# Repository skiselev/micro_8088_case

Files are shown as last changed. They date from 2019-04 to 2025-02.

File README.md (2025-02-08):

# Micro 8088 Case
Case for [Micro 8088](https://github.com/skiselev/micro_8088) and [ISA 8-Bit Backplane](https://github.com/skiselev/isa8_backplane) Based Computer

## Introduction
This case is intended to be used with [Micro 8088](https://github.com/skiselev/micro_8088)
and [ISA 8-Bit Backplane](https://github.com/skiselev/isa8_backplane) based computer.

The front panel features the standard [Intel* 9-pin front panel pinout](https://www.intel.com/content/www/us/en/support/articles/000007309/intel-nuc.html), and can work with other systems as well.

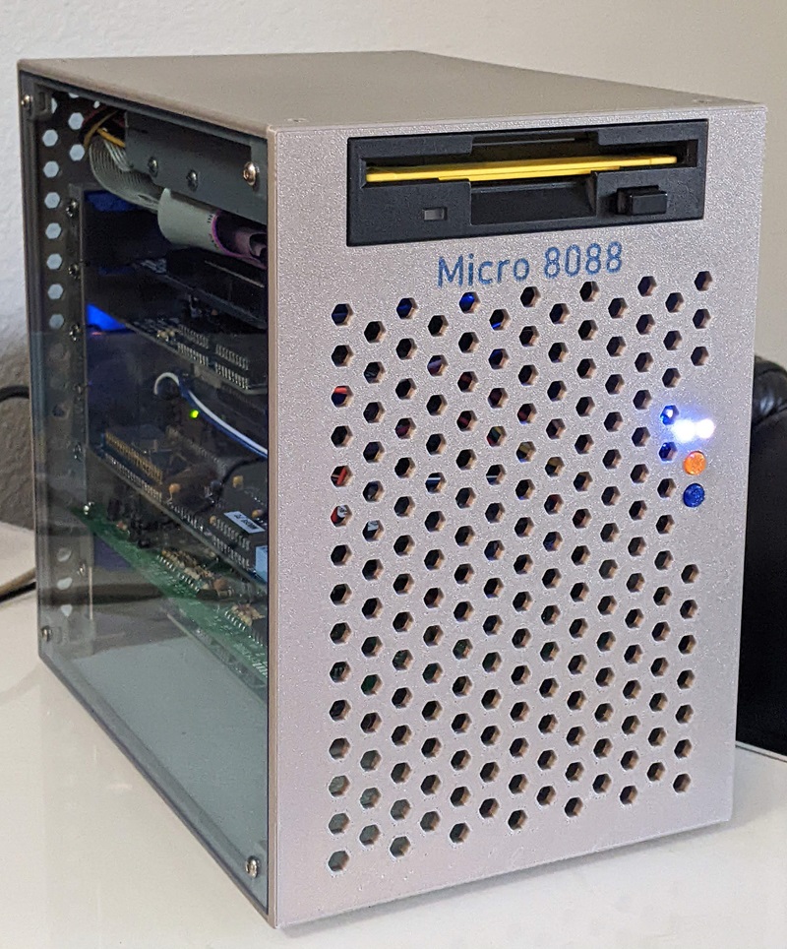
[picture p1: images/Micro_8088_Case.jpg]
Micro 8088 Case


## Hardware Documentation

### 3D Printed Parts

Parts can be printed using PETG or other fillament. The parts are designed to be printed without supports, with the exception of the case back, which needs supports for the DC power connector area.

Part            | File                                                                                               | Notes
--------------- | -------------------------------------------------------------------------------------------------- | ------------------------------------------------------------------
Case Front      | [case_front.stl](https://github.com/skiselev/micro_8088_case/blob/master/printed/case_front.stl)   | For the system name in colored letters, print sytem_name.stl first
Case Back       | [case_back.stl](https://github.com/skiselev/micro_8088_case/blob/master/printed/case_back.stl)     |
Case Bottom     | [case_bottom.stl](https://github.com/skiselev/micro_8088_case/blob/master/printed/case_bottom.stl) | Use supports on the build plate only option when printing
Case Top        | [case_top.stl](https://github.com/skiselev/micro_8088_case/blob/master/printed/case_top.stl)       | It is possible to use a 192.8 mm * 192.8 mm piece of transparent 1/8" / 3 mm acrylic plastic instead
Case Left       | [case_left.stl](https://github.com/skiselev/micro_8088_case/blob/master/printed/case_left.stl)     |
Case Right      | [case_right.stl](https://github.com/skiselev/micro_8088_case/blob/master/printed/case_right.stl)   |
ISA Slots Cover | [slots_cover.stl](https://github.com/skiselev/micro_8088_case/blob/master/printed/slots_cover.stl) | Snaps into the Case Back
Speaker Bracket | [speaker_bracket.stl](https://github.com/skiselev/micro_8088_case/blob/master/printed/speaker_bracket.stl) |
System Name     | [system_name.stl](https://github.com/skiselev/micro_8088_case/blob/master/printed/system_name.stl) | System Name "Micro 8088". Print and remove the rectangle on the perimeter. Next print case_front.stl
Keycaps         | [keycap_6mm_round.stl](https://github.com/skiselev/micro_8088_case/blob/master/printed/keycap_6mm_round.stl) | Print two using colorful plastic. It is recommended to print several keycaps at the time. [Omron B32-2000](https://www.mouser.com/ProductDetail/653-B32-2000) keycaps can be used instead

### Other Parts

Part                       | Quantity  | Notes
-------------------------- | --------- | -----
M3 x 8 mm flat head screws | 16        | Hold case sides together
M3 x 1.8 mm square nuts    | 16        | Hold case sides together
M3 x 8 mm pan head screws  | 6         | Floppy drive
M3 x 6 mm pan head screws  | 15        | Backplane - 6 screws, front panel - 2 screws, ISA cards - 7 screws

### Front Panel Schematic and PCB Layout

[Schematic - Version 1.0](KiCad/Micro_8088_Front_Panel-Schematic-1.0.pdf)

[PCB Layout - Version 1.0](KiCad/Micro_8088_Front_Panel-Board-1.0.pdf)

### Jumpers, Connectors, and Switches

#### J1 - Front Panel Connector
Pin | Description                  | Pin | Description
--- | ---------------------------- | --- | -------------------
1   | HDD Activity LED Anode (+)   | 2   | Power LED Anode (+)
3   |	HDD Activity LED Cathode (-) | 4   | Power LED Cathode (-)
5   |	Reset Switch (Ground)        | 6   | Power Switch (Output)
7   |	Reset Switch (Output)        | 8   | Power Switch (Ground)
9   |	5V (Unused)                  | 10  | Key (Pin removed)

#### SW1 - Power Switch
Press SW1 to turn on/off the system

#### SW2 - Reset Switch
Press SW2 to reset the system

### Front Panel Bill of Material

[Micro 8088 Front Panel project on Mouser.com](https://www.mouser.com/ProjectManager/ProjectDetail.aspx?AccessID=e9e37fe2f8) - View and order all components except of the PCB.
[Micro 8088 Front Panel project on OSH Park](https://oshpark.com/shared_projects/V4toeD34) - View and order the PCB.

Component type     | Reference | Description                       | Quantity | Possible sources and notes 
------------------ | --------- | --------------------------------- | -------- | --------------------------
PCB                |           | Micro 8080 Front Panel PCB V1.0   | 1        | OSH Park [Micro 8088 Front Panel V1.0](https://oshpark.com/shared_projects/V4toeD34)<br>Alternatively order from a PCB manufacturer of your choice using provided KiCad files
LED                | D1        | 3 mm, blue LED indicator          | 1        | Mouser [604-WP710A10QBC/D](https://www.mouser.com/ProductDetail/604-WP710A10QBC-D)<br>Alternatively use 3 mm green LED<br>Note: Intel* specifies a bi-color green/yellow LED
LED                | D2        | 3 mm, pink LED indicator          | 1        | Mouser [604-WP7104VRVCWA](https://www.mouser.com/ProductDetail/604-WP7104VRVCWA)<br>Alternatively use 3 mm yellow LED
Tactile Button     | SW1, SW2  | 6 mm tactile button, projected    | 2        | Mouser [653-B3F-1052](https://www.mouser.com/ProductDetail/653-B3F-1052), [653-B3F-1050](https://www.mouser.com/ProductDetail/653-B3F-1050)
Key Cap            | SW1, SW2  | Omron 6 mm round keycap, black    | 2        | Mouser [653-B32-2000](https://www.mouser.com/ProductDetail/653-B32-2000). Or use 3D printed keycaps
Pin Header         | J1        | 2x5 pin header, 2.54 mm pitch     | 1        | Mouser [855-M20-9980545](https://www.mouser.com/ProductDetail/855-M20-9980545)
Speaker            |           | 36 mm x 4.6 mm, 8 ohm, 1 W        | 1        | Mouser [665-AS03608MRLW100R](https://www.mouser.com/ProductDetail/665-AS03608MRLW100R)

### Front Panel Cables Bill of Material

Component type     | Reference | Description                           | Quantity      | Possible sources and notes 
------------------ | --------- | ------------------------------------- | ------------- | --------------------------
Connector          | J1        | 2x5 pin wire housing, 2.54 mm pitch   | 1             | Front panel connector. Mouser [855-M20-1070500](https://www.mouser.com/ProductDetail/855-M20-1070500)
Connector          |           | 4 pin wire housing, 2.54 mm pitch     | 2             | Speaker connector. Power switch and Power LED connector for the ISA 8-bit backplane. Mouser [855-M20-1060400](https://www.mouser.com/ProductDetail/855-M20-1060400)
Connector          |           | 2 pin wire housing, 2.54 mm pitch     | 2             | Reset switch connector. HDD LED connector. Mouser [855-M20-1060200](https://www.mouser.com/ProductDetail/855-M20-1060200)
Contact            |           | Female crimp contact                  | 20            | All connectors. Mouser [855-M20-1160042](https://www.mouser.com/ProductDetail/855-M20-1160042), [855-M20-1180042](https://www.mouser.com/ProductDetail/855-M20-1180042)
Wire               |           | 22 AWG - 26 AWG stranded wire, white  | 60 cm or 2'   | Negative wires for LEDs and switches
Wire               |           | 22 AWG - 26 AWG stranded wire, black  | 10 cm or 1/3' | Negative wire for the speaker
Wire               |           | 22 AWG - 26 AWG stranded wire, red    | 30 cm or 1'   | Positive wire for the speaker and the HDD LED
Wire               |           | 22 AWG - 26 AWG stranded wire, green  | 10 cm or 1/3' | Positive wire for the Power LED
Wire               |           | 22 AWG - 26 AWG stranded wire, blue   | 30 cm or 1'   | Positive wire for the Reset switch
Wire               |           | 22 AWG - 26 AWG stranded wire, yellow | 10 cm or 1/3' | Positive wire for the Power switch

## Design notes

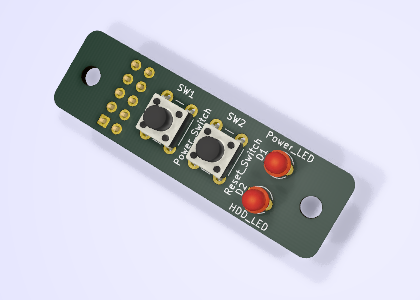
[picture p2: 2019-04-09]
images/Micro_8088_Front_Panel.png

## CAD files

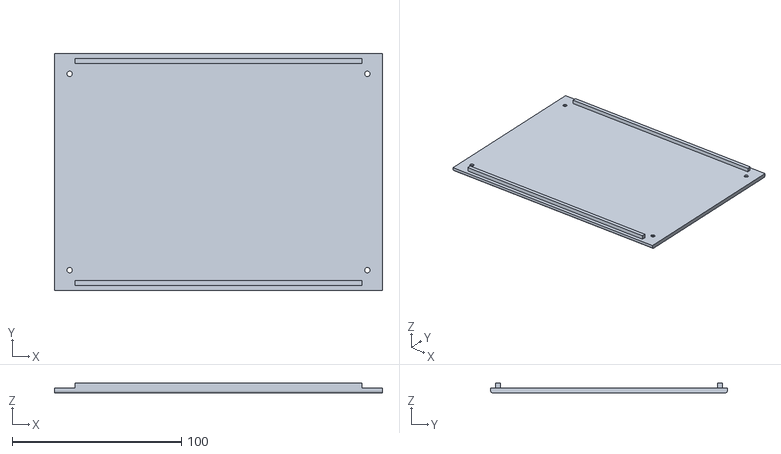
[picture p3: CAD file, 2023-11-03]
printed/case_left.stl
193.8 x 140.0 x 6.00

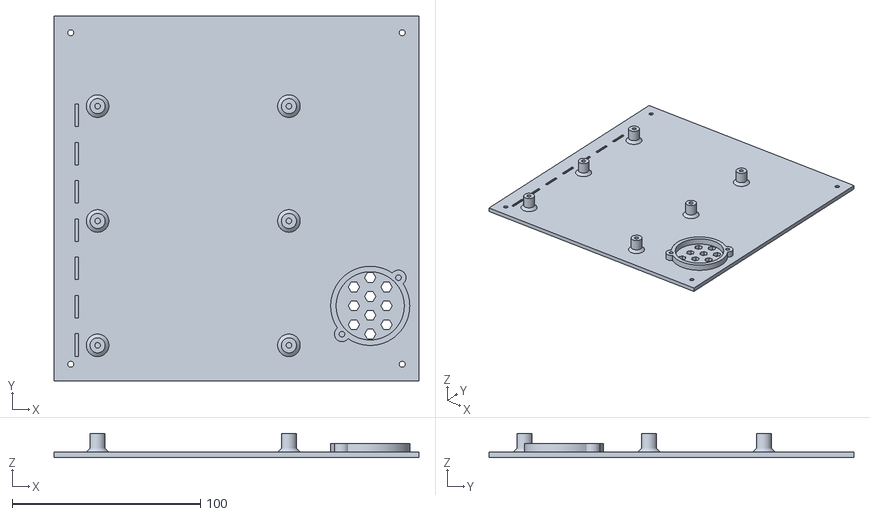
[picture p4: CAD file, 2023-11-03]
printed/case_bottom.stl
193.8 x 193.8 x 13.0

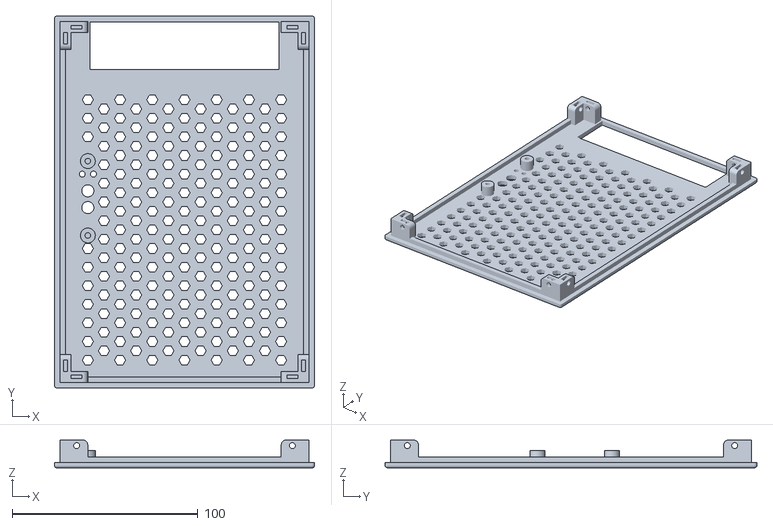
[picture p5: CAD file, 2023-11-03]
printed/case_front.stl
140.0 x 200.0 x 15.0

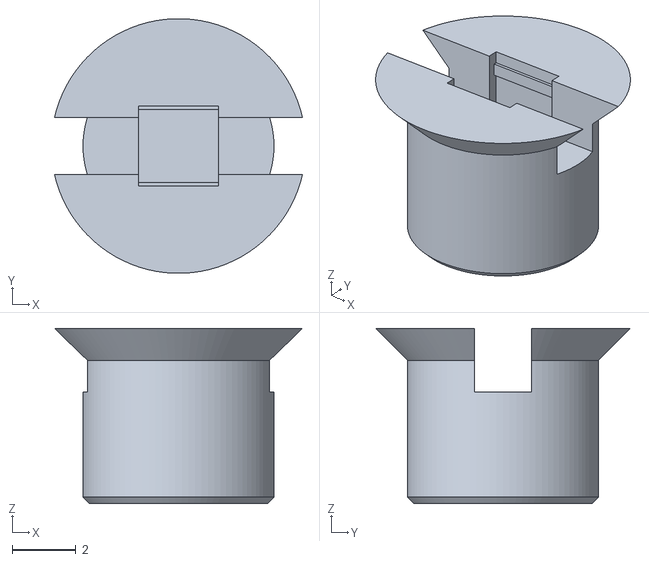
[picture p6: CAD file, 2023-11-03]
printed/keycap_6mm_round.stl
7.79 x 8.00 x 5.50

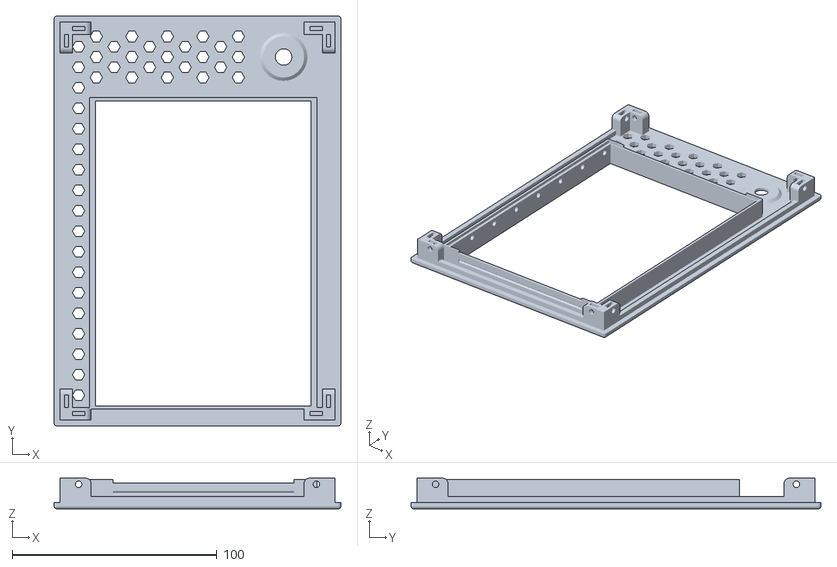
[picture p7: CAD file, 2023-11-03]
printed/case_back.stl
140.0 x 200.0 x 15.0

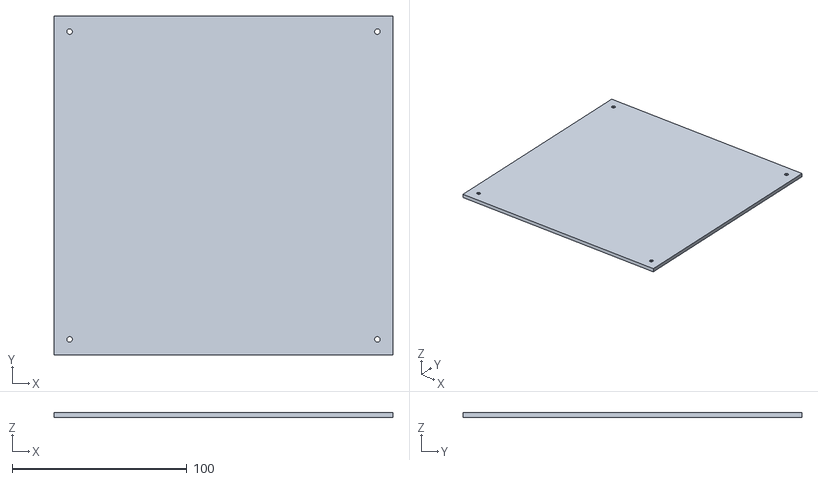
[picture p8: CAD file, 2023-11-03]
printed/case_top.stl
193.8 x 193.8 x 3.00

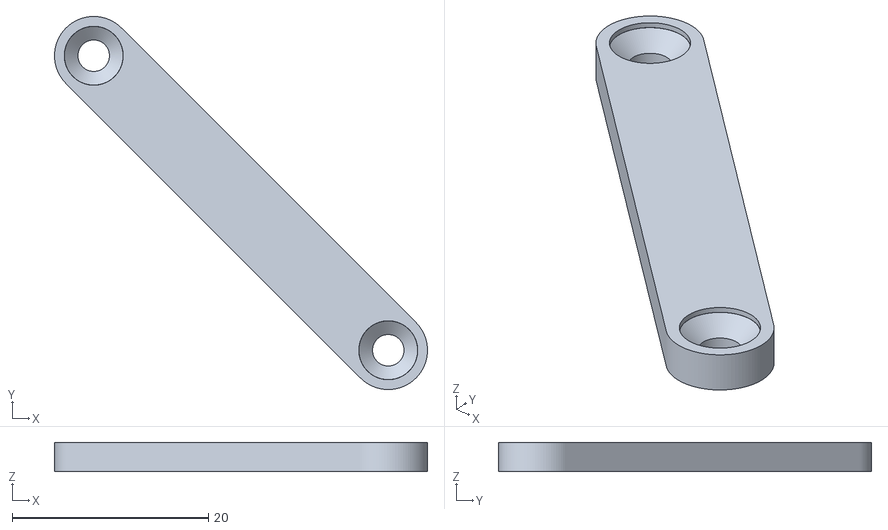
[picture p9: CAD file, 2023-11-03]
printed/speaker_bracket.stl
38.0 x 38.0 x 3.00

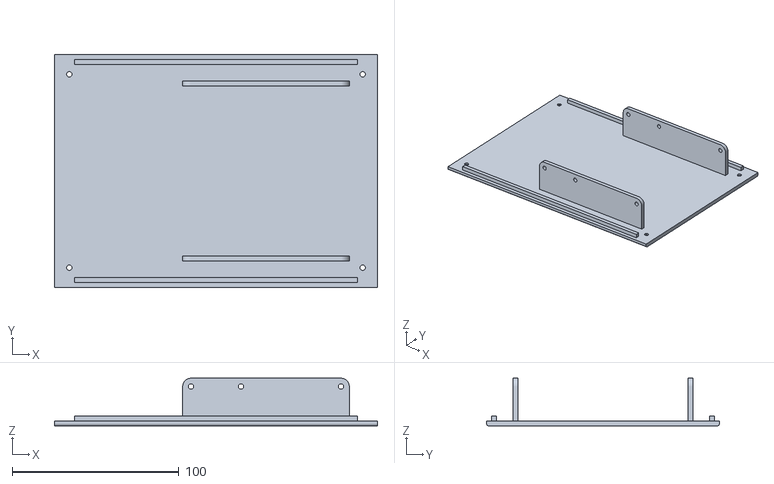
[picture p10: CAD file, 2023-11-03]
printed/case_right.stl
193.8 x 140.0 x 28.6

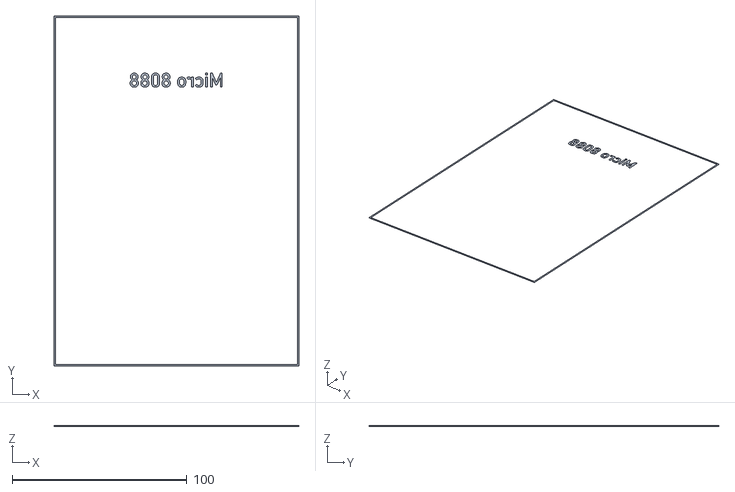
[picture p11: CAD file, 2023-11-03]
printed/system_name.stl
140.0 x 200.0 x 0.2

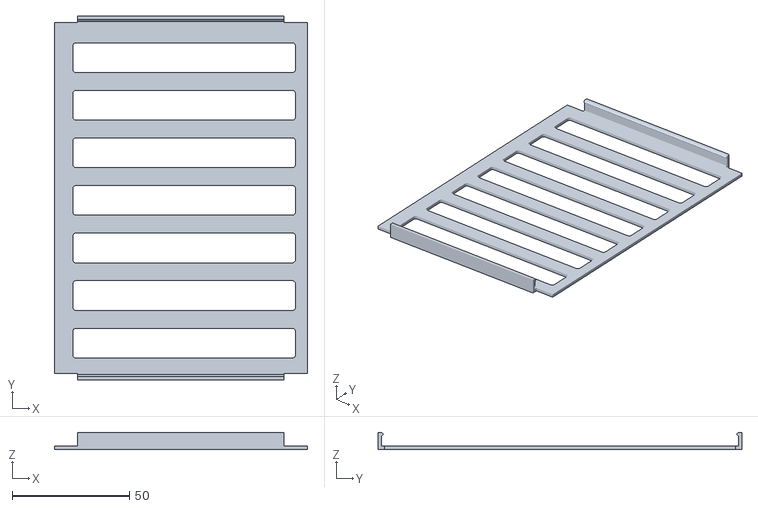
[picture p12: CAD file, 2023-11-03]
printed/slots_cover.stl
108.2 x 155.4 x 7.40

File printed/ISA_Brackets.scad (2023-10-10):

// ISA Bracket - Compatible with Keystone Electronics 9202
//
// Copyright (C) Sergey Kiselev <skiselev@gmail.com>
// Losely based on work by Arne Schmitz <arne.schmitz@me.com>

br_width = 18.4;
br_height = 120.02;
br_thick = 1.2;

cut_bottom_width = 4.11;
cut_bottom_height = 7.5;
//tolerance = 0.1;

br_height_wo_tongue = 112.78;
tongue_height = (br_height - br_height_wo_tongue);
tongue_width = 10.2;
tongue_cut_width = (br_width-tongue_width)/2;

tab_width=18.8;
tab_length=11.4;

cut_left_height=6;
cut_left_width=2.8;

append_right_height=2.5; // 3.2;
append_right_width=cut_left_width+tab_width-br_width;

tab_hole_diameter = 4.4;
tab_hole_y = tab_length+br_thick-6.35;
tab_hole_z = cut_left_width+tab_width-3.2;

pcb_mount_length = 8.9;
pcb_mount_width = 6.1;
pcb_mount_thick = 1;
pcb_mount_1_x = 31.75;
pcb_mount_2_x = pcb_mount_1_x + 56.52;

pcb_hole_y = 5.33;
pcb_hole_diameter = 2.8;

eth_height = 16.2; // 16.25
eth_width = 13.8;
eth_center_x = pcb_mount_1_x + 1.125 * 25.4;
eth_offset_z = 2.6;

// Bracket orientation: laying down on PCB mounts in card's (X-Y) plane
// Origin - top (ISA card oriented vertically) inside (closer to the PCB) corner

module eth_bracket() {
    difference() {
        // blank bracket
        blank_bracket();
        // cutout for the Ethernet connector
        eth_cutout();
    }
    // first PCB mount
    translate([pcb_mount_1_x,0,0]) {
        pcb_mount();
    }
    // second PCB mount
    translate([pcb_mount_2_x,0,0]) {
        pcb_mount();
    }
    // bottom reinforcement
    translate([cut_left_height+cut_left_width,0,0]) {
        rotate([0,0,270]) {
            rounded_cube_z2(3.5,pcb_mount_2_x+12.065-cut_left_height-cut_left_width,pcb_mount_thick,1);
        }
    }
    // top reinforcement
    translate([cut_left_height+cut_left_width,-1,br_width-1]) {
        cube ([pcb_mount_2_x+12.065-cut_left_height-cut_left_width,1,1]);
        translate([0,1,-1]) {
            rotate([45,0,0]) {
                cube([pcb_mount_2_x+12.065-cut_left_height-cut_left_width,sqrt(2),sqrt(2)]);
            }
        }
    }
}

module blank_bracket() {
    translate([0,0,0]) {
        difference() {
            union() {
                // the main bracket sheet
                cube([br_height_wo_tongue,br_thick,br_width]);
                // appendix - top right
                translate([0,0,br_width]) {
                    cube([append_right_height,br_thick,append_right_width]);
                }
                translate([append_right_height-append_right_width,0,br_width]) {
                    rotate([0,45,0]) {
                        cube([append_right_width*sqrt(2),br_thick,append_right_width*sqrt(2)]);
                    }
                }
                // mounting tab
                translate([-br_thick,0,cut_left_width]) {
                    //cube([br_thick,tab_length+br_thick,tab_width]);
                    rotate([90,0,90]) {
                        rounded_cube_z2(tab_length+br_thick,tab_width,br_thick,2);
                    }
                    translate([0,br_thick+tab_length-6.35,cut_left_width+tab_width]) {
                    }
                }
            }
            // cut corner towards the tongue (closer to PCB)
            translate([br_height_wo_tongue-tongue_cut_width,-tolerance,0]){
                rotate([0,45,0]) {
                    cube([tongue_cut_width*sqrt(2),br_thick+tolerance*2,tongue_cut_width*sqrt(2)]);
                }
            }
            // cut corner towards the tongue (farther from PCB)
            translate([br_height_wo_tongue-tongue_cut_width,-tolerance,br_width]){
                rotate([0,45,0]) {
                    cube([tongue_cut_width*sqrt(2),br_thick+tolerance*2,tongue_cut_width*sqrt(2)]);
                }
            }
            // cutout - top left
            translate([-tolerance,-tolerance,-tolerance]) {
                cube([cut_left_height+tolerance,br_thick+tolerance*2,cut_left_width+tolerance]);
            }
            translate([cut_left_height-cut_left_width,-tolerance,0]) {
                rotate([0,45,0]) {
                    cube([cut_left_width*sqrt(2),br_thick+tolerance*2,cut_left_width*sqrt(2)]);
                }
            }
            // mounting tab - slot for the screw
            translate([-br_thick-tolerance,tab_hole_y,tab_hole_z]) {
                rotate([0,90,0]) {
                    cylinder(d=tab_hole_diameter,h=br_thick+tolerance*2,$fn=64);
                }
                translate([0,-tab_hole_diameter/2,0]) {
                    cube([br_thick+tolerance*2,tab_hole_diameter,3.2+tolerance]);
                }
            }
        }
    }
    // the tongue
    translate([br_height_wo_tongue,br_thick,tongue_cut_width]) {
        //cube([tongue_height,br_thick,tongue_width]);
        rotate([90,0,0]) {
            rounded_cube_z2(tongue_height,tongue_width,br_thick,2);
        }
    }
}

module pcb_mount() {
    difference () {
        translate([-pcb_mount_width/2,0,0]) {
            rotate([0,0,270]) {
                rounded_cube_z2(pcb_mount_length,pcb_mount_width,1,pcb_mount_thick);
            }
        }
        translate([0,-pcb_hole_y,-tolerance]) {
            cylinder(d=pcb_hole_diameter,h=pcb_mount_thick+tolerance*2,$fn=64);
        }
    }
}

// Cutout for Ethernet modular connector
module eth_cutout() {
      translate([eth_center_x-eth_height/2,-tolerance,eth_offset_z]) {
          cube([eth_height,br_thick+tolerance*2,eth_width]);
      }
}

// rounded_cube_z2 - draws a "cube" with two rounded corners
// it is assumed that the cube lays in the X-Y plane
// and the rounded corner is in Z axis
module rounded_cube_z2(x,y,z,r) {
    union() {
        cube([x-r,y,z]);
        hull() {
            translate([x-r,r,0]) {
                cylinder(r=r,h=z,$fn=64);
            }
            translate([x-r,y-r,0]) {
                cylinder(r=r,h=z,$fn=64);
            }
        }
    }
}

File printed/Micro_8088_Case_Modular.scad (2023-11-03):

// 3D Printed Case for the Micro 8088 system
//
// Copyright (C) 2019 - 2023 Sergey Kiselev.
//
// This program is free software: you can redistribute it and/or modify
// it under the terms of the GNU General Public License as published by
// the Free Software Foundation, either version 3 of the License, or
// (at your option) any later version.
//
// This program is distributed in the hope that it will be useful,
// but WITHOUT ANY WARRANTY; without even the implied warranty of
// MERCHANTABILITY or FITNESS FOR A PARTICULAR PURPOSE.  See the
// GNU General Public License for more details.
//
// You should have received a copy of the GNU General Public License
// along with this program.  If not, see <http://www.gnu.org/licenses/>.


// set only one of the variables below to true to draw the respective part
generate_preview = true;
render_back = false;
render_front = false;
render_bottom = false;
render_top = false;
render_left = false;
render_right = false;
render_slots_cover = false;
render_speaker_bracket = false;
render_keycap = false;
render_system_name = false;

// All dimensions are in mm
// Case size: depth - 200 mm * width = 200 mm, * height = 140 mm
// case outside dimensions
case_depth=200;
case_width=200;
case_height=140;
case_thickness=3.0;
// case inside dimensions
inside_height=case_height-case_thickness*2;
inside_depth=case_depth-case_thickness*2;
inside_width=case_width-case_thickness*2;
corner_radius=case_thickness/2;
nut_inserts_radius = 2.6;       // corner radius for nut inserts
bracket_thickness=1.6;       // thickness of the material around ISA brackets
pcb_thickness=1.6;
in2mm=25.4;                  // mm per inch
mb_to_case_back=0.065*in2mm;
mb_to_case_left=5.06;       // carefully adjusted so that ISA brackets don't touch the nut inserts and there is 8 mm space between backplane and floppy drive
mb_to_left_slot=0.558*in2mm; // distance between the left edge of motherboard to the center of the leftmost slot cut-out
slot_height=0.61*in2mm;
slot_spacing=0.8*in2mm;  // distance between ISA slots
card_height=3.9*in2mm;   // height of an ISA card, not including edge connector
card_to_bracket_top=3.65*in2mm; // ISA card bottom to the top of the bracket
bracket_depth=0.45*in2mm;    // depth of an ISA bracket (top part inside)
bracket_height=card_to_bracket_top+slot_height;             // height of an ISA bracket (motherboard to top part inside)
bracket_width=0.72*in2mm; // width of an ISA bracket
tongue_cutout_width=12; // width of a cutout for the tongue of an ISA bracket

bracket_tab_offset = (0.740+0.110)*in2mm-bracket_width; // offset of the bracket tab relative to the bracket's left side
slots=7;                // number of slots
slots_area_width=slots*slot_spacing+bracket_tab_offset*2; // width of slots plus a bit more
slots_area_left=mb_to_case_left+mb_to_left_slot-bracket_width/2-bracket_tab_offset; // distance from the inside left wall to slots area
echo("bracket_tab_offset", bracket_tab_offset);
echo("slots_area_width", slots_area_width);

standoff_height=10;
standoff_radius=4;
m3_hole_radius=3.2/2;
m3_tap_hole_radius=3.0/2;
m3_head_radius=3;
floppy_width=101.6;
floppy_height=25.4;
floppy_depth=145;
floppy_mount_height=5;
floppy_mount_depth_1=21;
floppy_mount_depth_2=floppy_mount_depth_1+60;
floppy_mount_depth_3=floppy_mount_depth_1+90;
floppy_bezel_depth=4;
floppy_to_case_right=25.6; // bottom (left) of the floppy drive to inside right of the case
tolerance=0.1;

dc_socket_x=inside_height-25;   // relative to case inner top
dc_socket_y=180-case_thickness; // relative to case inner left

// speaker
speaker_radius=36/2;
speaker_height=4.5;
speaker_to_case_back=inside_depth-speaker_radius-case_thickness-5;
speaker_to_case_left=speaker_radius-case_thickness+25;

// distance between ventilation holes
vent_hole_radius=3;
vent_holes_horiz_step=10;
vent_holes_vert_step=sin(60)*vent_holes_horiz_step;

// case front panel settings
vent_holes_start_height=(case_height-12*vent_holes_vert_step)/2;
front_panel_width = 50;
front_panel_height = 14;
// center of the front panel
front_panel_x = vent_holes_start_height;
front_panel_y = case_width/2+2;
// the keycaps should stick out for 0.5 mm
front_panel_standoff_height=10-case_thickness-0.5;
button_radius = 3.25;
led_radius = 1.6;

// number of faces in circular objects
$fn=90;

echo("Space above ISA cards", inside_height-standoff_height-pcb_thickness-slot_height-card_height);
echo("Maximal ISA card length", inside_depth-bracket_depth-mb_to_case_back);
echo("Space between backplane and floppy", case_width-case_thickness*2-mb_to_case_left-6.1*in2mm-floppy_to_case_right);

include <ISA_Brackets.scad>


if (render_back) {
    case_back();
}
if (render_front) {
    case_front();
}
if (render_bottom) {
    case_bottom();
}
if (render_top) {
    case_top();
}
if (render_left) {
    case_left();
}
if (render_right) {
    case_right();
}
if (render_slots_cover) {
    slots_cover();
}
if (render_speaker_bracket) {
    rotate([180,0,0]) {
        speaker_bracket();
    }
}
if (render_keycap) {
    rotate([180,0,0]) {
        keycap_6mm_round();
    }
}
if (render_system_name) {
    system_name(true);
}


if (generate_preview) {
    // back panel
    translate([0,0,case_height]) {
        rotate([0,90,0]) {
            color("cyan") case_back();
        }
    }
    translate([case_thickness+bracket_depth,case_thickness+slots_area_left,case_thickness+standoff_height+pcb_thickness]) {
        rotate([0,-90,0]) {
            color("blue") slots_cover();
        }
    }
    translate([case_thickness,case_thickness,0]) {
        color("orange") case_bottom();
    }
    // top panel
    translate([case_thickness,case_width-case_thickness,case_height]) {
        rotate([180,0,0]) {
            color("blue") case_top();
        }
    }
    // left panel
    translate([case_thickness,0,case_height]) {
        rotate([-90,0,0]) {
            color("green") case_left();
        }
    }
    // right panel
    translate([case_thickness,case_width,0]) {
        rotate([90,0,0]) {
            color("red") case_right();
        }
    }

    // front panel and related objects
    // translate to move front panel forward
    translate([case_depth,0,0]) {
        // rotate front panel from X-Y plane to Y-Z plane
        rotate([0,-90,0]) {
            // front panel
            color ("silver") case_front();
            // keycaps for switches
            translate([front_panel_x,front_panel_y,5]) {
                // keycap for the left (power) button
                translate([0,4,0]) {
                    rotate([0,180,0]) {
                        color("blue") keycap_6mm_round();
                    }
                }
                // keycap for the left (power) button
                translate([0,-5,0]) {
                    rotate([0,180,0]) {
                        color("orange") keycap_6mm_round();
                    }
                }
            }   
            
            // system name text
            system_name(false);
            
        }
    }

    // motherboard and ISA brackets
    translate([case_thickness,case_thickness,case_thickness]) {
        // motherboard translate
        translate([mb_to_case_back+bracket_depth,mb_to_case_left,standoff_height]) {
            mb();
        }
        // ISA bracket
        translate([bracket_depth+br_thick,mb_to_case_left+mb_to_left_slot-br_width/2,standoff_height+pcb_thickness+bracket_height]) {
            rotate([90,90,180]) {
                eth_bracket();
            }
        }
    }
    // floppy drive
    translate([case_depth-floppy_depth-floppy_bezel_depth,case_width-floppy_to_case_right-case_thickness,(case_height-floppy_width)/2]) {
        floppy_drive();
    }

    // speaker bracket
    translate([speaker_to_case_back+case_thickness,speaker_to_case_left+case_thickness,speaker_height+case_thickness*2]) {
        rotate([180,0,90]) {
            color("purple") speaker_bracket();
        }
    }
}

module case_back() {
    vent_holes_top_height=vent_hole_radius+6;
    vent_holes_start_width=(inside_width-18*vent_holes_horiz_step)/2-5;
    
    bracket_top_offset=0.11*in2mm;
    hole_y=-bracket_width/2+bracket_top_offset+0.74*in2mm-0.125*in2mm;
    hole_z=0.25*in2mm;
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

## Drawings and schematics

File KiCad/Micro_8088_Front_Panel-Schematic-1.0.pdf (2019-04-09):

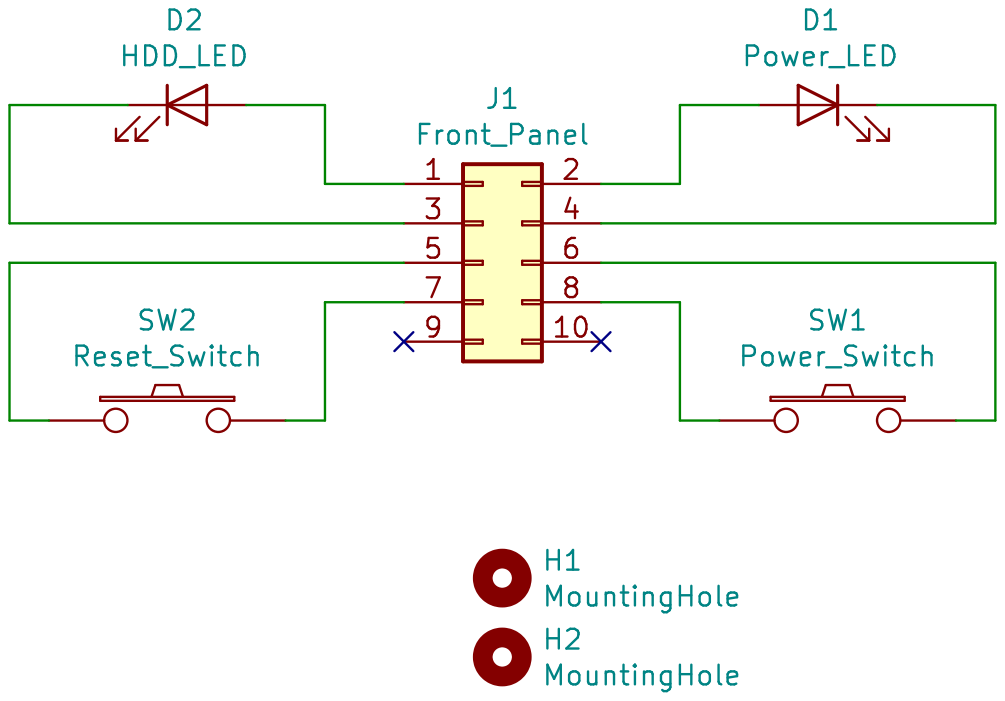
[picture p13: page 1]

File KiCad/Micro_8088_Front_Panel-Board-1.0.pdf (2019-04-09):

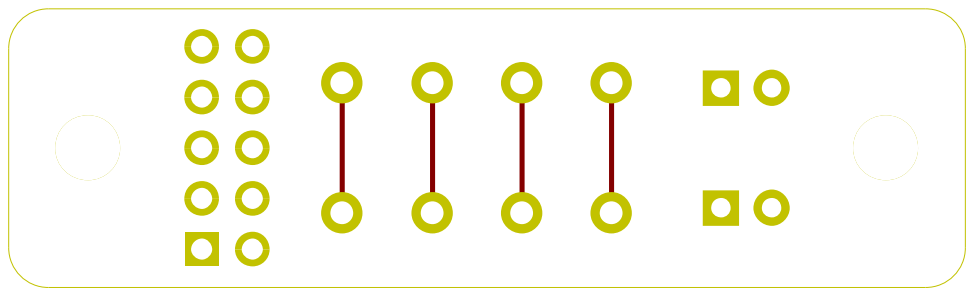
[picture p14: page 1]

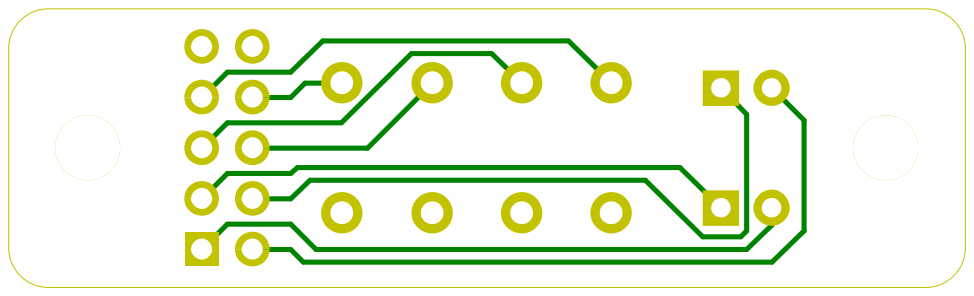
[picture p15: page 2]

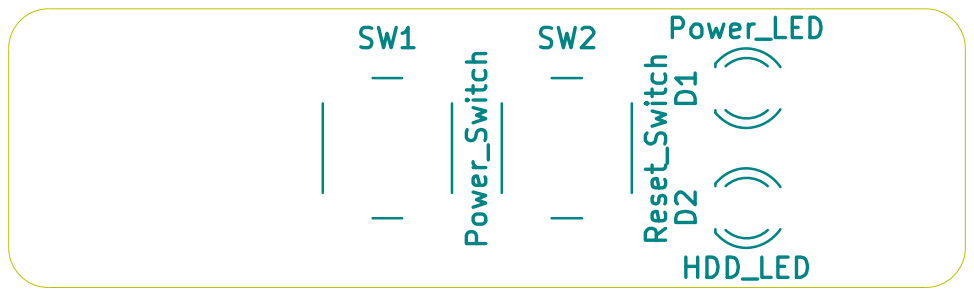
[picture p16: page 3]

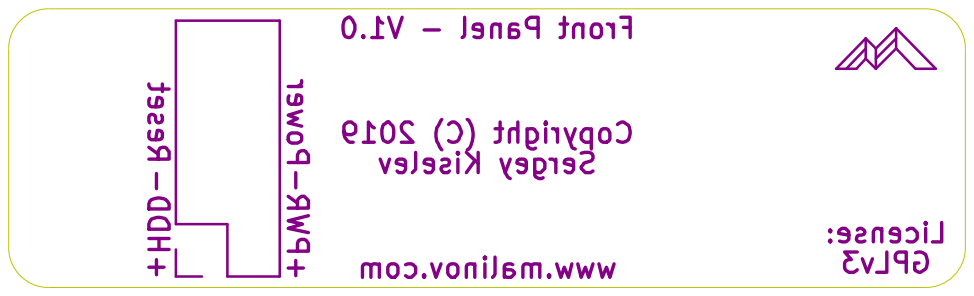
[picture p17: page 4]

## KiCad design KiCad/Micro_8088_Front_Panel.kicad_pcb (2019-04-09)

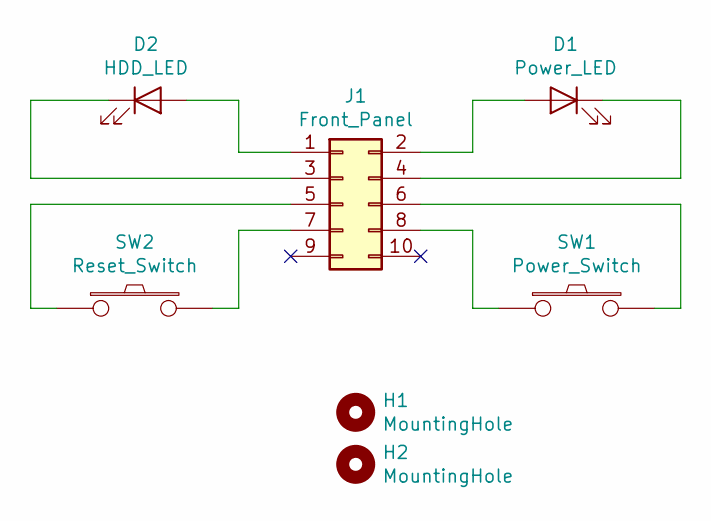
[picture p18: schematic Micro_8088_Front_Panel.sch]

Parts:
D1: Power_LED; LED_D3.0mm
D2: HDD_LED; LED_D3.0mm
H1, H2: MountingHole; MountingHole_3.2mm_M3_DIN965
J1: Front_Panel; PinHeader_2x05_P2.54mm_Vertical
SW1: Power_Switch; SW_PUSH_6mm_H7.3mm
SW2: Reset_Switch; SW_PUSH_6mm_H7.3mm

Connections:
unnamed: D1.1 (K), J1.4
unnamed: D1.2 (A), J1.2
unnamed: D2.1 (K), J1.3
unnamed: D2.2 (A), J1.1
unnamed: J1.5, SW2.1
unnamed: J1.6, SW1.2
unnamed: J1.7, SW2.2
unnamed: J1.8, SW1.1

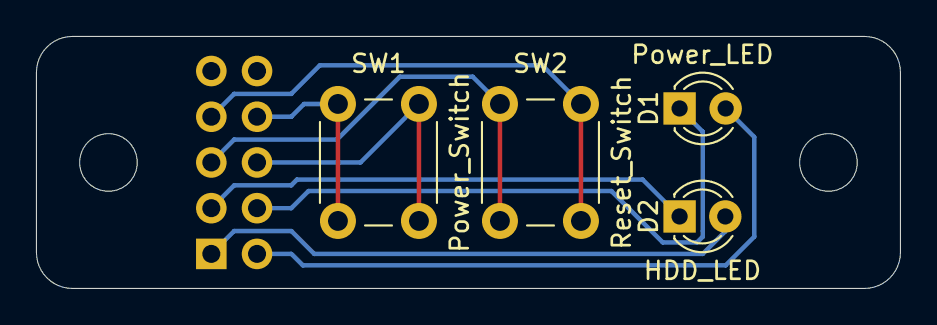
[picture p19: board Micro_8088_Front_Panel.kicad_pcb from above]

Board: 2 copper layers, 48.0 x 14.0 mm, 7 parts (1 on the bottom side), 8 nets.

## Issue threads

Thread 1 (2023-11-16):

Top and Right 3D print files seem to be swapped

wrljet, 2023-11-16:
Sergey,

The 3D files for the Top and Right seem to be swapped, contents vs. the names.

Bill

skiselev, 2023-11-16:
Hi Bill,

I guess it depends how do you place the case. The parts are named as if the case was laying down on the "bottom", that is the side where the backplane is attached.
Of course the way I took the picture, the top becomes left, and the right becomes top, etc. Everything is rotate 90 degrees counterclockwise.

Let me know if I missed something here.

Thanks,
Sergey

wrljet, 2023-11-16:
OK, I understand now.  That explains a few other questions I had.

Bill

Closed 2023-11-16.

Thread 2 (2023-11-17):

Dead link to Intel Front Panel Pinout

wrljet, 2023-11-17:
Sergey, the link to the Intel Front Panel Pinout in the README appears to be dead.

I found this [page](https://www.intel.com/content/www/us/en/support/articles/000007309/intel-nuc.html?wapkw=front%20panel%20pinout), which shows the 9-pin (10 with a key) pinout you're using.

You have to expand the little dropdown doodad though on the page to see the 9-pin diagram.

Bill

skiselev, 2023-11-17:
Fixed. Also added the BOM for the front panel cables, in case people want to build their own instead of using ready made female jumper cables

Closed 2023-11-17.

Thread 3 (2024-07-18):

What speaker?

ab0tj, 2024-07-18:
Just curious... Do you have a part number for a speaker that fits the case? I tried finding one with the right diameter and also thin enough to fit under the bracket... No luck.

Thanks!

skiselev, 2025-02-08:
I guess better late than never...
It is a 36 mm x 4.6 mm speaker. There are several on Mouser.com.
I used this one: https://www.mouser.com/ProductDetail/665-AS03608MRLW100R

I updated the BoM: https://github.com/skiselev/micro_8088_case/commit/3c061c79c2f5782b22bd9095b27af0d4f897806c

Closed 2025-02-08.

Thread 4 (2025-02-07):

Step files?

prime6809, 2025-02-07:
Would you considder providing .step files as well as .stl files, as they are much easier to pull into a CAD package and customise if wanted?

Cheers.

Phill.

skiselev, 2025-02-08:
The design is done using OpenSCAD. The OpenSCAD files are included in this repository.
It appears that OpenSCAD does not support generating .step files, but perhaps FreeCAD can?
See https://wiki.freecad.org/Import_OpenSCAD_code

Please let me know if that works for you

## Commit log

2019-04-09 Populate the repository with KiCad design files
    [Micro_8088_Front_Panel.kicad_pcb, Micro_8088_Front_Panel.sch]
2019-04-09 README: Add links to schematic and PCB layout
2019-04-09 README: Add note about bi-color LEDs
2019-04-09 KiCad: Add PDF printouts
    [Micro_8088_Front_Panel.sch]
2023-10-10 Add OpenSCAD files for the case
    [ISA_Brackets.scad, Micro_8088_Case_Modular.scad]
2023-10-10 Cleanup - remove old modules
    [Micro_8088_Case_Modular.scad]
2023-10-10 Add conditions to print separate parts; Move slots_cover to X-Y plane
    [Micro_8088_Case_Modular.scad]
2023-10-10 Clean up OpenSCAD code, add STL files
    [case_back.stl, case_bottom.stl, case_front.stl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]
2023-10-10 Clean up OpenSCAD code
    [Micro_8088_Case_Modular.scad]
2023-10-10 Upload a photo of the case
2023-10-10 Update README.md - Add case parts description
2023-11-03 Use 3.0 mm thickness for the case walls
    [Micro_8088_Case_Modular.scad, case_back.stl, case_bottom.stl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]
2023-11-03 Replace case photo with a new one
2023-11-17 Fix front panel pinout link. Add BOM for the front panel cables
2025-02-08 README: Add speaker to the BOM

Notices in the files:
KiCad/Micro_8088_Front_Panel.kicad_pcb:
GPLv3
